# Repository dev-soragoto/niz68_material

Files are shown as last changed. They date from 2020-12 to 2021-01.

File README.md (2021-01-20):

# niz68_material

### 改装niz68键盘的一些模型

1. 改装整体目标
    1. 替换硅胶碗为rf硅胶碗
    2. 替换原装定位板，其他零件均不变
    3. ~~设计新的定位板，使用rf的rgb轴体替换原装轴体~~
        - ~~rf的rgb轴边长似乎为14.3且顶部需有开槽, 定位板不与原装兼容~~
        - 计划无限期延后,原因是我润过轴换过定位板之后觉得手感比rf好
    4. 3d打印外壳

1. 改装进度
    - 硅胶碗已替换
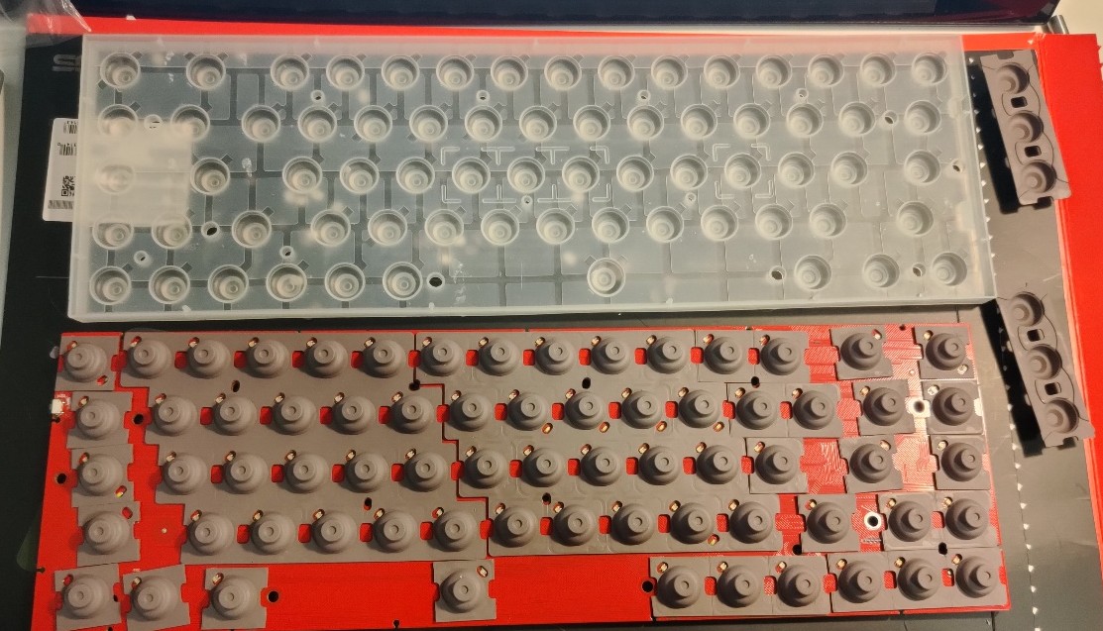
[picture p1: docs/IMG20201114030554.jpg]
rf硅胶碗
    
        - 不太喜欢niz原厂静音圈的声音，去掉静音圈之后有了新的问题，推杆高度不够键帽有点晃
        - 原厂静音圈厚度0.8左右，去工厂定制了0.8厚度的硅胶带背胶垫片，已经贴在推杆下面
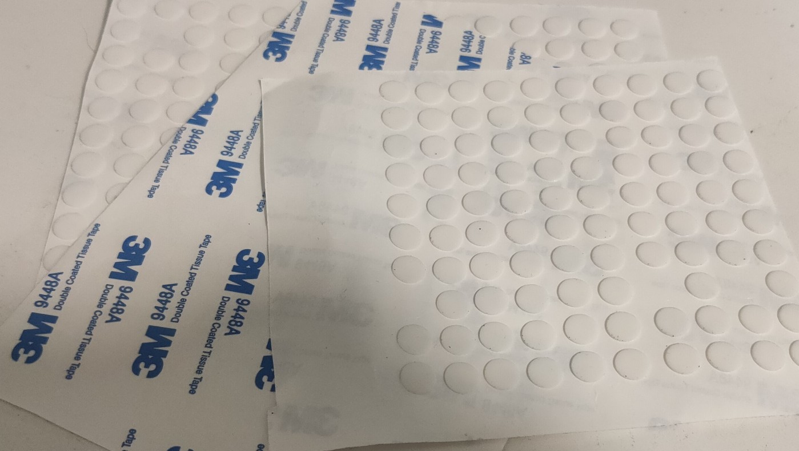
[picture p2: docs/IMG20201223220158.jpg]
垫片
        
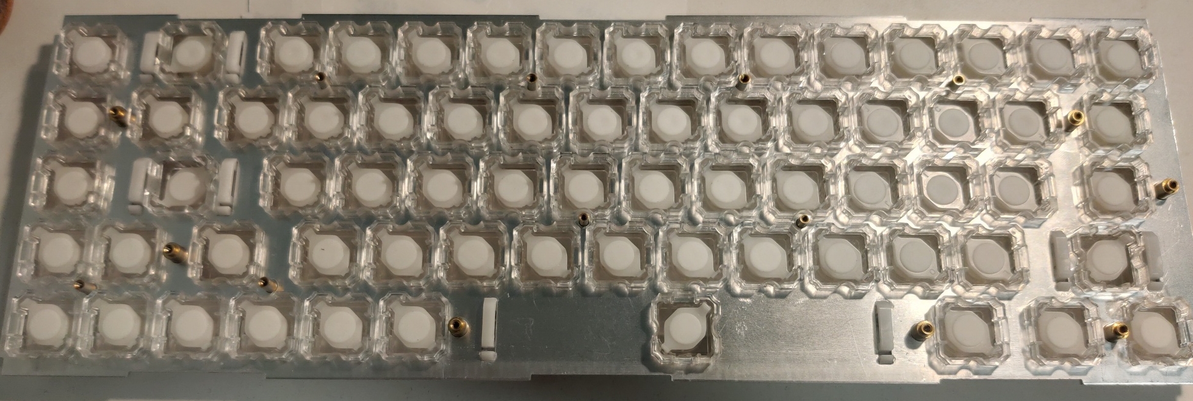
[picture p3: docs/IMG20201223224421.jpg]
处理后推杆
        
        - 目前手感基本等于hhkb非静音版,体感上推杆比rfrgb稳定
    - 非标螺柱已交付工厂打样
        - 螺柱没有问题, 可以正常使用
    - 定位板已成功替换,目前表现完美
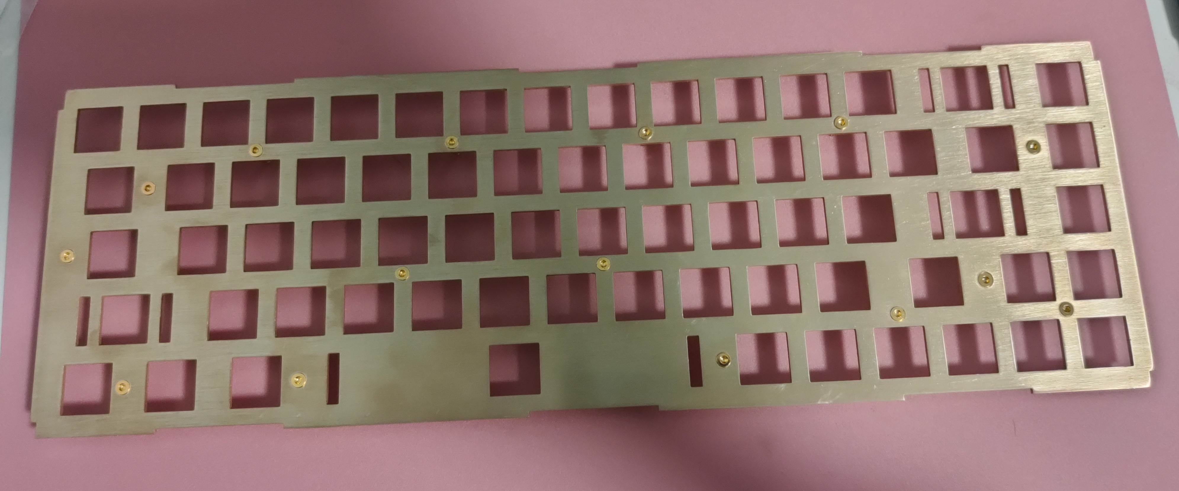
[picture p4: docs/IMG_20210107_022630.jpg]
定位板正面
    
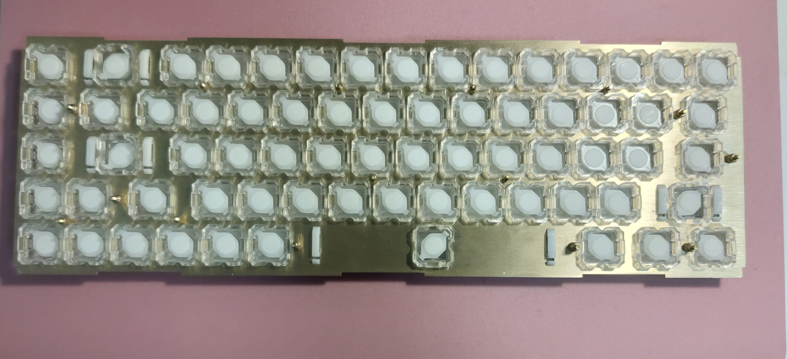
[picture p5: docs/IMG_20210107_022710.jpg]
定位板背面
    
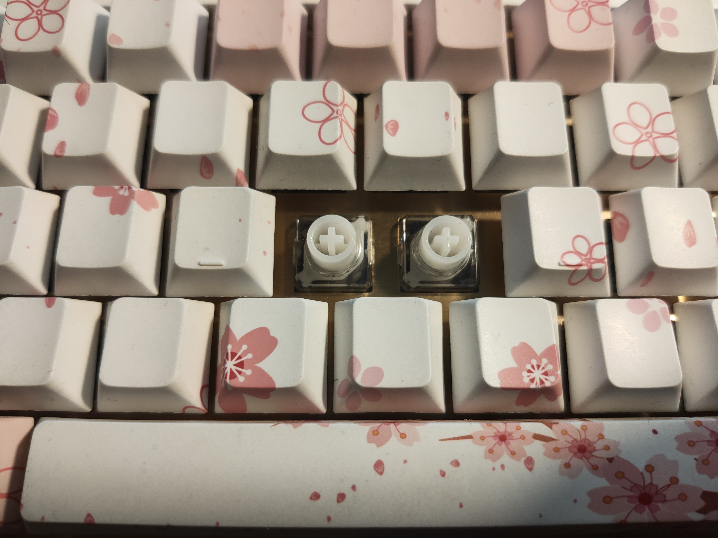
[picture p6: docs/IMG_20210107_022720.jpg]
上机
    

    - 2021/1/15: 得知niz官方定位板上的方孔尺寸为14.1x14.1,故进一步更改图纸,更改前图纸的尺寸为14x14
    - 2021/1/17: 官方壳子逆向完成并做了一些更改
    - 2021/1/20: 壳子虽然能用,不过孔位和厚度都有一些问题需要微调
    **暂时不要拿模型直接3d打印**

3. 文件夹及文件说明

dwg文件采用cad2021绘制, 不确定低版本兼容性

```
├── ./docs                              文档相关
├── ./LICENSE                           协议
├── ./plate                             定位板相关
│   ├── ./plate/非标螺柱.bak
│   ├── ./plate/非标螺柱.dwg             定位板上螺柱
│   ├── ./plate/niz68.bak
│   ├── ./plate/niz68.dwg               定位板
│   └── ./plate/plot.log
├── ./plate                             手托
├── ./shell                             外壳
└── ./README.md
```

4. 定位板设计

    - 标准定位板采用压铆螺柱链接做支撑，不方便小量设计
    - 图中直接采用非标螺柱进行支撑，使用m2沉头螺丝和m2螺母进行固定
    - 非标螺柱可3d打印, 不过最好使用cnc

5. 为了适配windows下触摸板, 3d打印了手托, 目前手感优秀没有误触
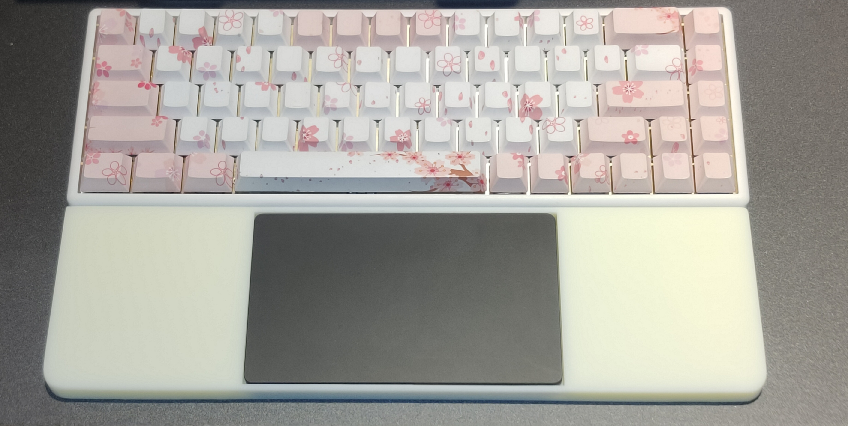
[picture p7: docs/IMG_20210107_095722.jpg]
手托

    - 3d打印文件见文件夹说明
    - 3d打印文件分减重版和实心版,减重版可以节省一些打印费用,后续可以通过预留的孔加入配重.~~还是别这么玩了,省不了多少钱还麻烦的一笔~~
    - 注意：**这里的触摸板不是mac的触摸板**, mac触摸板的尺寸不是这样的.~~这个触摸板为 brydge w-touch 这个广告没给我打钱, 所以划掉了~~

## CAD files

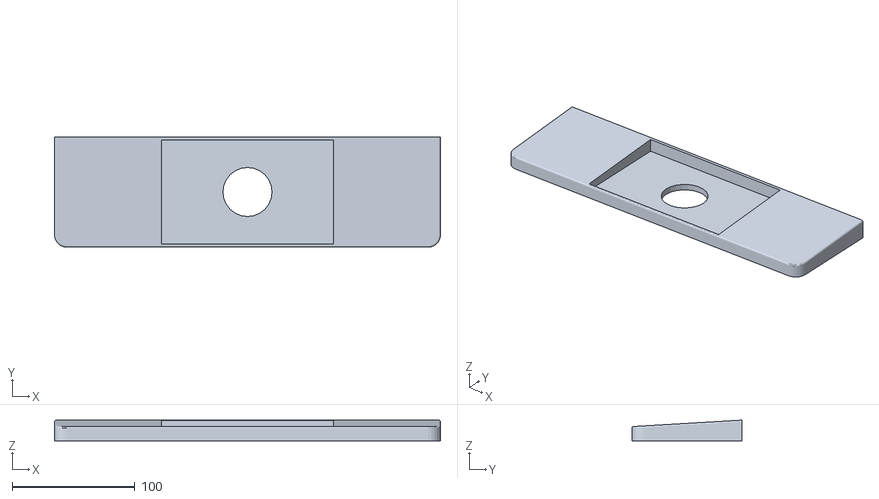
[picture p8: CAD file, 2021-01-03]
holder/holder.stl
315.0 x 90.0 x 17.0

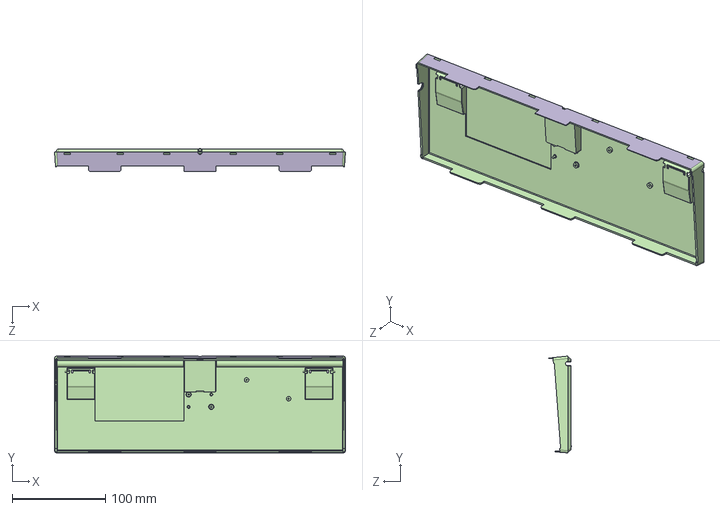
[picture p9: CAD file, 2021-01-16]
shell/shell-down.STEP
312.5 x 104.0 x 25.1 mm

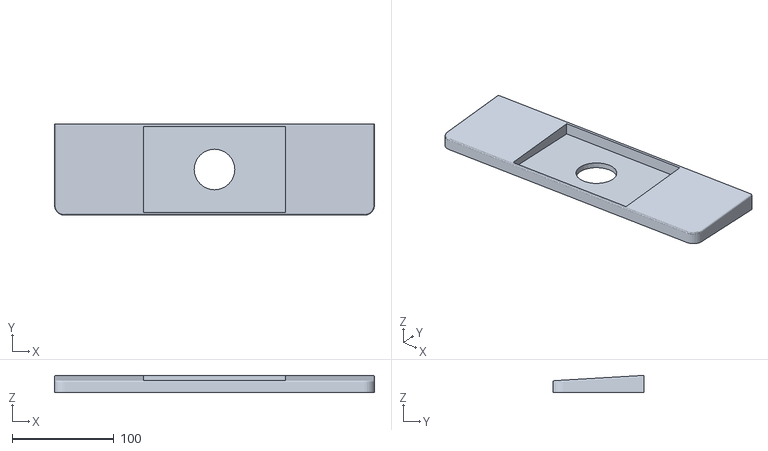
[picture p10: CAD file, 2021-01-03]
holder/holder_light.stl
315.0 x 90.0 x 17.0

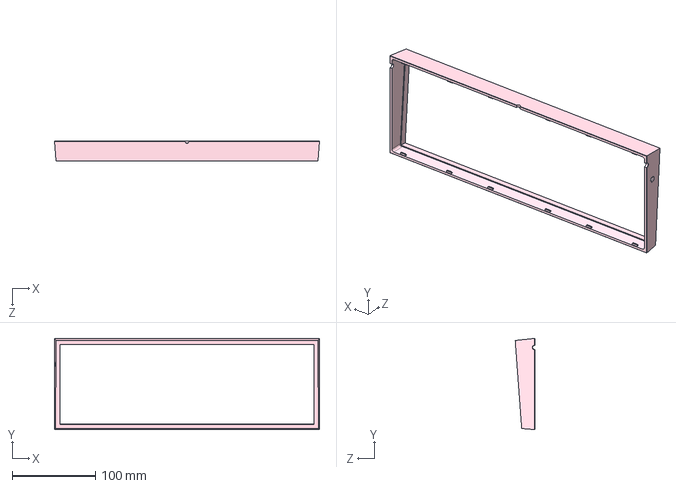
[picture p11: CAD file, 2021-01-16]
shell/shell-up-change.STEP
317.8 x 109.3 x 23.5 mm

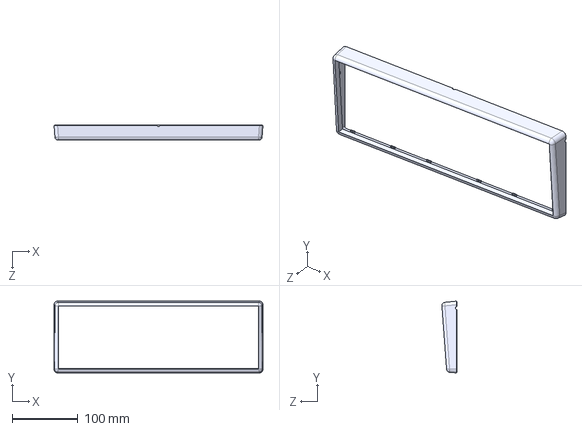
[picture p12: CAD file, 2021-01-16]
shell/shell-up.STEP
317.7 x 109.1 x 23.2 mm

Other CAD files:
plate/niz68.dwg
plate/非标螺柱.dwg
holder/holder.dwg
holder/holder_light.dwg
shell/shell-down.SLDPRT
shell/shell-down.STL
shell/shell-up-change.SLDPRT
shell/shell-up-change.STL
shell/shell-up.SLDPRT
shell/shell-up.STL

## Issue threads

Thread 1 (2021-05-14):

niz68魔改外壳询问

pkingpeng, 2021-05-14:
你这里面的图片好像打不开，我也会niz68想考虑整个外壳，能看看你的魔改效果吗，感谢！

soragotosann, 2021-06-03:
> 你这里面的图片好像打不开，我也会niz68想考虑整个外壳，能看看你的魔改效果吗，感谢！

你可以尝试直接把整个项目clone下来，github国内有墙可能是挺慢的，不过我得那个外壳的图纸不是很准确，你可能需要自己修改， 直接拿去用的话可能有问题，定位板是可以直接用的

Closed 2024-04-25.

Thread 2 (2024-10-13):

定位板

UndefBhvr, 2024-10-13:
老哥换定位板麻烦吗，一直想换个碳定

dev-soragoto, 2024-10-13:
> 老哥换定位板麻烦吗，一直想换个碳定

我感觉还行吧 一个一个拆轴和推杆挺费事的 不过没啥难度 你自己拆了看看吧

UndefBhvr, 2024-10-13:
ok谢谢捏，现在暂时先用原厂，有空了去切个碳定看看

dev-soragoto, 2024-10-13:
> ok谢谢捏，现在暂时先用原厂，有空了去切个碳定看看

好的 那issue我就关掉了

Closed 2024-10-13.

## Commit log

2020-12-20 fix plate
    [niz68.dwg]
2020-12-21 fix 螺丝
    [niz68.dwg, 非标螺柱.dwg]
2021-01-01 fix bug
    [niz68.dwg]
2021-01-01 fix readme, dwg
    [niz68.dwg]
2021-01-03 fix holder
    [holder.dwg, holder.stl]
2021-01-03 fix holder_light
    [holder.dwg, holder.stl, holder_light.dwg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]
2021-01-15 定位板开孔改为14.1
    [niz68.dwg]
2021-01-16 增加3d打印外壳
    [shell-down.SLDPRT, shell-down.STEP, shell-down.STL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]
